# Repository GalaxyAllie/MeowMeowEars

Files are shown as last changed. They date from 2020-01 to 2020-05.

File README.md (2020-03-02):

# Meow Meow Ears

This is a project to create a pair of programmable neko mimis that feature ten LEDs.

## WARNINGS - *max power draw* and *brightness* and *health*

Please be aware that the LEDs can *easily* exceed the max power draw of this circuit design. It is highly recommended not to exceed 150 mA. They're cat ears, you don't need to blind everyone - keep the NeoPixel library brightness down to around 50 or so, tops :)

Also be aware some people are *photo sensitive* - these are meant for rave environments. For environments where people may not expect flashing lights (and where they do...) *please be considerate*.

## Basic Features

- ATSAMD21 microcontroller (ARM Cortext M0)
- Ten WS2812b RGB LEDs
- Power and status LEDs
- One capacitive touch zone - though this isn't used in the example code
- Native USB (you can even use it as a keyboard, hopefully)
- Designed to be put in cat ear headbands. Meow!
- Probably a fair number of bugs and bad design decisions!

## Copyright/Liability

I licence this work under [CC BY-SA 4.0](https://creativecommons.org/licenses/by-sa/4.0/#)

Also, I'm obviously not responsible for injuries or anything like that - this is definitely not a safety-tested, commercial project. Build at your own risk. It probably won't even work :)

## Build Notes

You really shouldn't draw over 50 mA or so of power, you're probably blinding people if you do :) - see warnings above. Thus, you should be fine to input all the way up to the linear regulator max voltage rating of 6V - but you're wasting energy over 3.3V. Thus, 3x NiMH batteries or a 3.7V Lion battery would be good power choices - be smart and sensible though. Batteries can be dangerous. There is no hardware over-discharge protection, so use only batteries with this protection!

Boards can be ordered from [Osh Park](https://oshpark.com/shared_projects/LssyuQtY) - that's not an affiliate link or anything, just a convenient source. And they're purple.

I have forked and modified the Adafruit Trinket M0 file from the Microsoft USB Mass Storage [Bootloader](https://github.com/MermaidAllie/uf2-samdx1/tree/master/build/alliecat_meowmeowears) for the ATSAMD21. The Trinket M0 bootloader also works, tho!

## Bill of Materials

| Component | Manufacturer | Qty |
|---|---|-----|
| This board | Whoever you choose | 1 |
| ATSAMD21E18A-AU-ND | Microchip Technology | 1 |
| S2B-PH-SM4-TB(LF)(SN) | JST | 1 |
| 0.1uF 0603 Capacitor | Any | 10  |
| 1uF 0603 Capacitor | Any | 2 |
| 10uF 0603 Capacitor | Any | 2 |
| WS2812b LED | Worldsemi | 10  |
| UV/blacklight LED 0805 (or fave :) ) | Generic | 2 |
| AP2112K-3.3TRG1 | Diodes Incorporated | 1 |
| BAT54-TP | Micro Commercial Co | 2 |
| USB3076-30-A | GCT | 1 |
| 510 Ohm 0805 Resistor (diff if UV sub)  | Any | 2 |
| 330 Ohm 0805 Resistor | Any | 1 |
| 3.5 x 6 mm push button switch | Generic | 1 |

## Example Code

The example C++/Arduino code is designed to pretend the board is an Adafruit Trinket M0, and is for use with the Trinket M0 bootloader.

## Thanks

Thank you to the following people:

- Ladyada and [Adafruit](https://learn.adafruit.com/how-to-program-samd-bootloaders/trinket-m0-wiring) - for building excellent products and teaching people electronics. I used a lot of Trinket M0's in prototyping this. Seriously, people, go buy their products - they're fantastic (and the boards are way cuter than some others, especially look at the Metro M4 Express - it's just adorable).

- [OpenMoji](https://www.openmoji.org) - this is the source of the emoji used on the board silk.

- Q - for being an awesome friend who has helped with so much of the EDA side of working this all out. Thank you for answering late night messages with silly questions!

- JoJo Siwa - because the inspirational quote comes from one of your songs, and your concert on the [D.R.E.A.M. tour](https://www.jojodreamtour.com/) I went to in Cardiff was amazing. I'm not sure if it's your original quote tho, so I didn't quote it as you - I think I've heard it before? Either way, very inspiring performance! Keep things fun and positive and spread the positive energy, people!

## Version History

### v1

This was essentially a light strip on a cat ear shaped PCB.

### v2

This added an ATSAMD21 microcontroller.

### v3

This is the release version - it fixes the major bugs and makes them ready for general use.

### v3b

Minor update - reset on back where it's useful, more room to insert battery... not much else :)

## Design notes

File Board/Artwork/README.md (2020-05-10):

# Meow Meow Ears Artwork

## OpenMoji

[OpenMoji](https://www.openmoji.org) is the source of the emoji used on the board silk. I have copied the files used in here so you know the source, but please visit OpenMoji to get them for anything you need. OpenMoji are licensed under [CC-BY-SA 4.0](https://creativecommons.org/licenses/by-sa/4.0/#), the same license I use for all my work on this project :) 

## Edge Cuts

The edge cuts files are available as both SVG and [Affinity Designer](https://affinity.serif.com/en-gb/designer/) files.

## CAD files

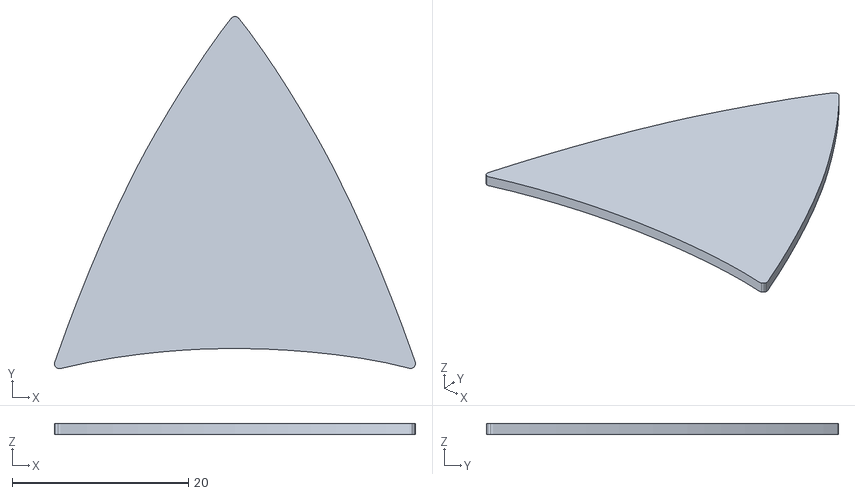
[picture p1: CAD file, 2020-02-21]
Board/Diffuser/Meow Meow Ears - Window.stl
41.0 x 40.0 x 1.20

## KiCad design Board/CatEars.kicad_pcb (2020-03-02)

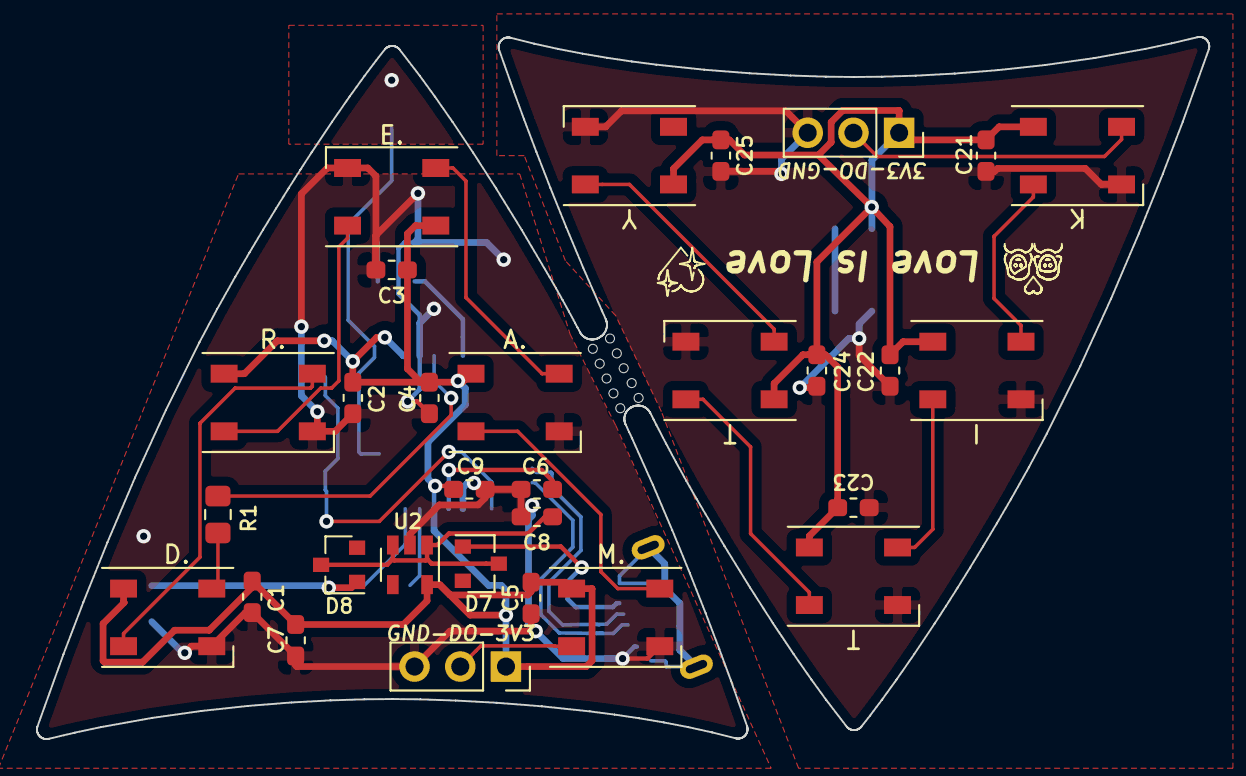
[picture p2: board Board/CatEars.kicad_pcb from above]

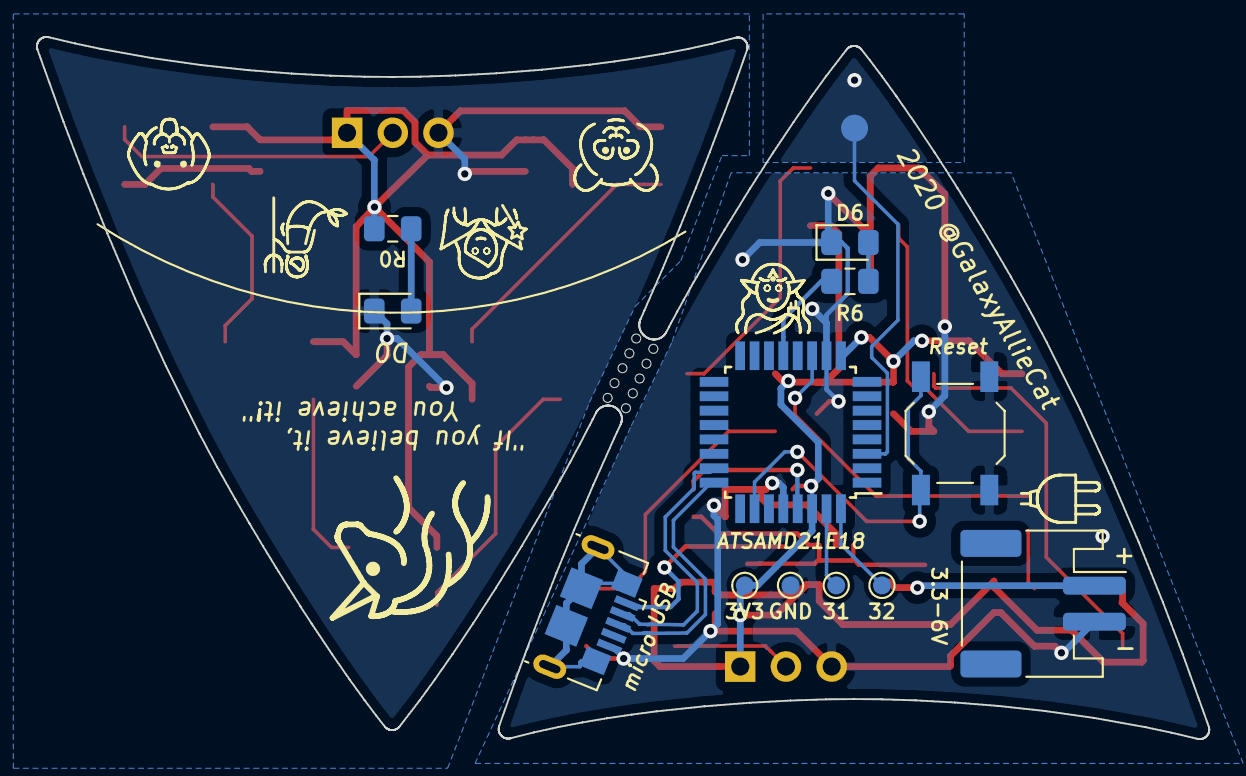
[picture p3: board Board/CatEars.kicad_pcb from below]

Board: 2 copper layers, 65.1 x 39.0 mm, 43 parts (13 on the bottom side), 29 nets.

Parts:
3V3, 31, 32: Conn_01x01; TestPoint_Pad_D1.0mm
3V3-DO-GND: Conn_01x03; PinSocket_1x03_P2.54mm_Vertical
A.: WS2812B; LED_WS2812B_PLCC4_5.0x5.0mm_P3.2mm
ATSAMD21E18: ATSAMD21E18A-AU; TQFP-32_7x7mm_P0.8mm
BT1: Battery; JST_PH_S2B-PH-SM4-TB_1x02-1MP_P2.00mm_Horizontal
C1, C2, C3, C4, C5, C21, C22, C23, C24, C25: 0.1 uF C; C_0603_1608Metric_Pad1.05x0.95mm_HandSolder
C6, C9: 1 uF C; C_0603_1608Metric_Pad1.05x0.95mm_HandSolder
C7, C8: 10 uF C; C_0603_1608Metric_Pad1.05x0.95mm_HandSolder
D0, D6: LED; LED_0805_2012Metric_Pad1.15x1.40mm_HandSolder
D7, D8: D_Schottky; D_SOT-23_ANK
D.: WS2812B; LED_WS2812B_PLCC4_5.0x5.0mm_P3.2mm
E.: WS2812B; LED_WS2812B_PLCC4_5.0x5.0mm_P3.2mm
GND: Conn_01x01; TestPoint_Pad_D1.0mm
GND-DO-3V3: Conn_01x03; PinSocket_1x03_P2.54mm_Vertical
H1: MountingHole_Pad; TestPoint_Pad_D1.5mm
I: WS2812B; LED_WS2812B_PLCC4_5.0x5.0mm_P3.2mm
K: WS2812B; LED_WS2812B_PLCC4_5.0x5.0mm_P3.2mm
M.: WS2812B; LED_WS2812B_PLCC4_5.0x5.0mm_P3.2mm
R0, R6: 510 R; R_0805_2012Metric_Pad1.15x1.40mm_HandSolder
R1: 330 R; R_0805_2012Metric_Pad1.15x1.40mm_HandSolder
R.: WS2812B; LED_WS2812B_PLCC4_5.0x5.0mm_P3.2mm
Reset: SW_Push; SW_SPST_TL3342
T: WS2812B; LED_WS2812B_PLCC4_5.0x5.0mm_P3.2mm
T#2: WS2812B; LED_WS2812B_PLCC4_5.0x5.0mm_P3.2mm
U2: AP2112K-3.3; SOT-23-5
Y: WS2812B; LED_WS2812B_PLCC4_5.0x5.0mm_P3.2mm
micro USB: USB_B_Micro; USB_Micro-B_GCT_USB3076-30-A

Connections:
+3V3: 3V3.1, A..1, ATSAMD21E18.9, ATSAMD21E18.30, C1.1, C2.1, C3.1, C4.1, C5.1, C7.2, C9.1, D..1, E..1, GND-DO-3V3.1, M..1, R..1, U2.5
+BATT: BT1.1, D8.2
/USB_D+: ATSAMD21E18.24, micro USB.3
/USB_D-: ATSAMD21E18.23, micro USB.2
GND: A..3, ATSAMD21E18.10, ATSAMD21E18.28, BT1.2, C1.2, C2.2, C3.2, C4.2, C5.2, C6.1, C7.1, C8.2, C9.2, D6.1, D..3, E..3, GND.1, GND-DO-3V3.3, M..3, R..3, Reset.2, U2.2, micro USB.5
unnamed: ATSAMD21E18.29, C6.2
unnamed: C8.1, D7.1, D8.1, U2.1, U2.3
unnamed: 3V3-DO-GND.1, C21.1, C22.1, C23.1, C24.1, C25.1, I.1, K.1, R0.2, T.1, T#2.1, Y.1
unnamed: 3V3-DO-GND.3, C21.2, C22.2, C23.2, C24.2, C25.2, D0.1, I.3, K.3, T.3, T#2.3, Y.3
unnamed: D0.2, R0.1
unnamed: D..2, R..4
unnamed: D..4, R1.2
unnamed: E..4, R..2
unnamed: A..4, E..2
unnamed: A..2, M..4
unnamed: GND-DO-3V3.2, M..2
unnamed: D6.2, R6.2
unnamed: I.4, K.2
unnamed: 3V3-DO-GND.2, K.4
unnamed: I.2, T.4
unnamed: T.2, T#2.4
unnamed: T#2.2, Y.4
unnamed: ATSAMD21E18.3, H1.1
unnamed: 31.1, ATSAMD21E18.31
unnamed: 32.1, ATSAMD21E18.32
unnamed: ATSAMD21E18.11, R1.1
unnamed: ATSAMD21E18.13, R6.1
unnamed: ATSAMD21E18.26, Reset.1
VBUS: D7.2, micro USB.1

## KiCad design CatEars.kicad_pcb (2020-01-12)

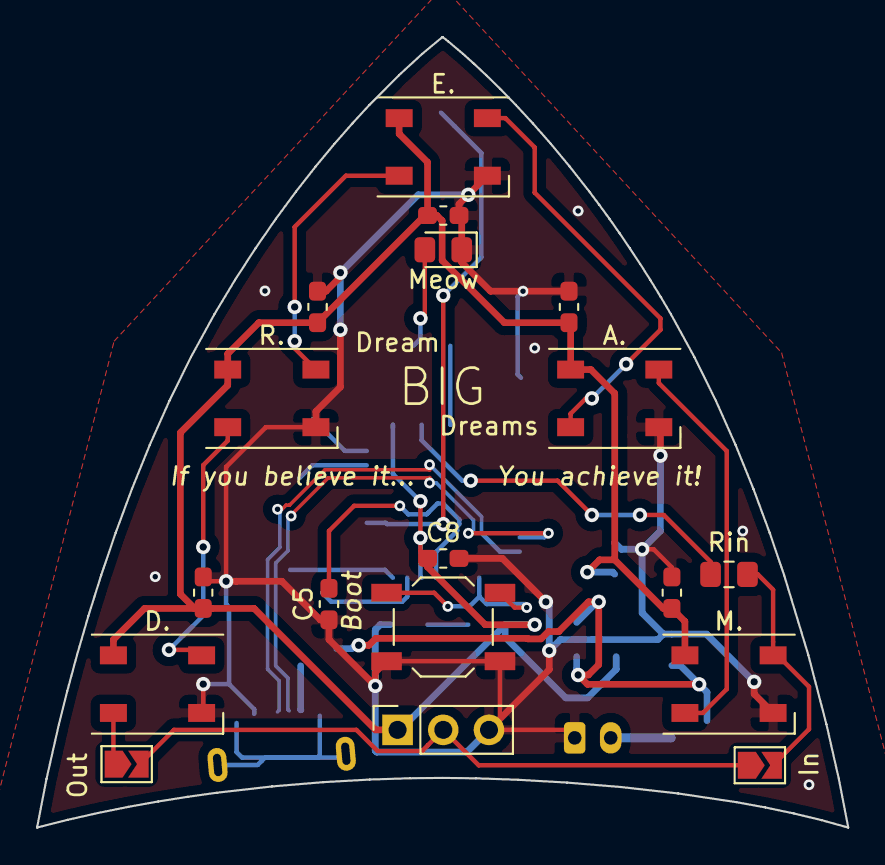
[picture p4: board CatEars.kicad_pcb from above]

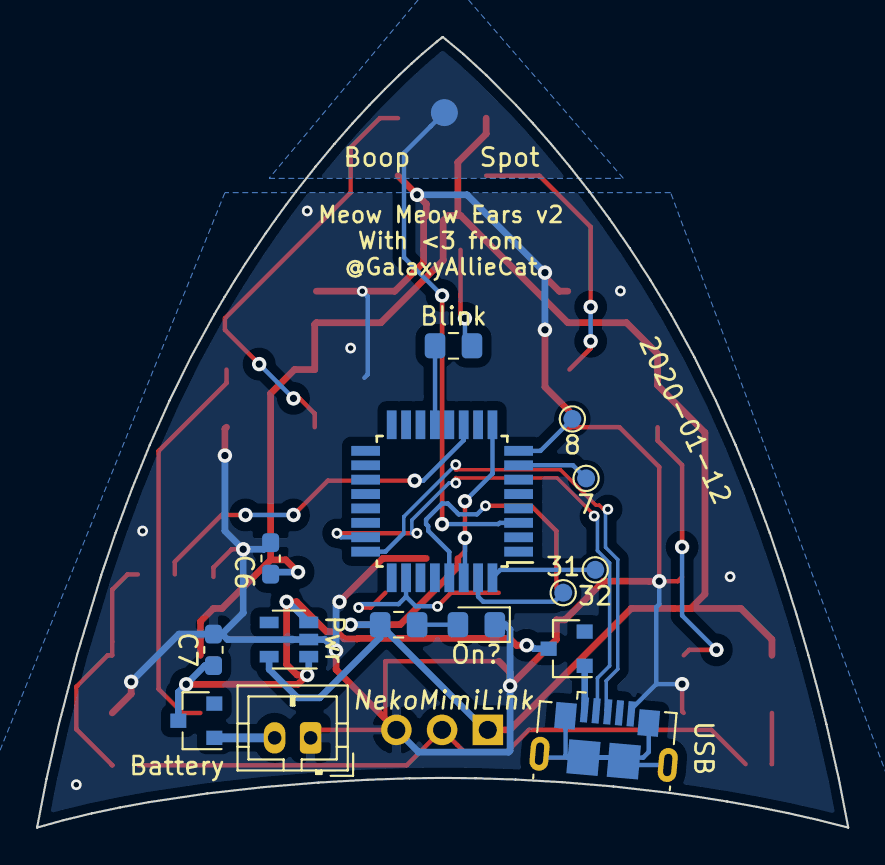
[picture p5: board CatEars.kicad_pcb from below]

Board: 2 copper layers, 45.1 x 43.9 mm, 34 parts (16 on the bottom side), 25 nets.

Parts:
7, 8, 31, 32: Conn_01x01; TestPoint_Pad_D1.0mm
:): USB_B_Micr; USB_Micro-B_GCT_USB3076-30-A
A.: WS2812B; LED_WS2812B_PLCC4_5.0x5.0mm_P3.2mm
Battery: Conn_01x02_Male; JST_PH_B2B-PH-K_1x02_P2.00mm_Vertical
Battery#2: D_Schottky; D_SOT-23_ANK
Blink: R; R_0805_2012Metric_Pad1.15x1.40mm_HandSolder
Boot: SW_Push; SW_SPST_TL3342
C0, C1, C2, C3, C4, C5, C6, C7, C8: C; C_0603_1608Metric_Pad1.05x0.95mm_HandSolder
D.: WS2812B; LED_WS2812B_PLCC4_5.0x5.0mm_P3.2mm
E.: WS2812B; LED_WS2812B_PLCC4_5.0x5.0mm_P3.2mm
H1: MountingHole_Pad; TestPoint_Pad_D1.5mm
In: SolderJumper_2_Open; SolderJumper-2_P1.3mm_Open_TrianglePad1.0x1.5mm
J3: Conn_01x03; PinSocket_1x03_P2.54mm_Vertical
M.: WS2812B; LED_WS2812B_PLCC4_5.0x5.0mm_P3.2mm
Meow: LED; LED_0805_2012Metric_Pad1.15x1.40mm_HandSolder
On?: LED; LED_0805_2012Metric_Pad1.15x1.40mm_HandSolder
Out: SolderJumper_2_Open; SolderJumper-2_P1.3mm_Open_TrianglePad1.0x1.5mm
Pwr: AP2112K-3.3; SOT-23-5
R2: R; R_0805_2012Metric_Pad1.15x1.40mm_HandSolder
R.: WS2812B; LED_WS2812B_PLCC4_5.0x5.0mm_P3.2mm
Rin: R; R_0805_2012Metric_Pad1.15x1.40mm_HandSolder
U1: ATSAMD21E18A-AU; TQFP-32_7x7mm_P0.8mm
USB: D_Schottky; D_SOT-23_ANK

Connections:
+3V3: A..1, C0.1, C1.1, C2.1, C3.1, C4.1, C6.1, C8.1, D..1, E..1, J3.1, M..1, Pwr.5, R2.1, R..1, U1.9, U1.30
+BATT: Battery.2, Battery#2.2
/USB_D+: :).3, U1.24
/USB_D-: :).2, U1.23
GND: :).5, A..3, Battery.1, Boot.2, C0.2, C1.2, C2.2, C3.2, C4.2, C5.1, C6.2, C7.2, C8.2, D..3, E..3, J3.3, M..3, Meow.1, On?.1, Pwr.2, R..3
unnamed: C5.2, U1.29
unnamed: Battery#2.1, C7.1, Pwr.1, Pwr.3, USB.1
unnamed: A..4, M..2
unnamed: In.2, M..4, Rin.2
unnamed: A..2, E..4
unnamed: E..2, R..4
unnamed: D..4, R..2
unnamed: D..2, Out.1
unnamed: Blink.2, Meow.2
unnamed: On?.2, R2.2
unnamed: H1.1, U1.3
unnamed: In.1, J3.2, Out.2
unnamed: 31.1, U1.31
unnamed: 32.1, U1.32
unnamed: 8.1, U1.8
unnamed: 7.1, U1.7
unnamed: Blink.1, U1.13
unnamed: Rin.1, U1.11
unnamed: Boot.1, U1.26
VBUS: :).1, USB.2

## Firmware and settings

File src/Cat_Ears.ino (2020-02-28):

// Sample Arduino code for Meow Meow Ears v3 with Adafruit Trinket M0 bootloader/Arduino board
// Uncomment the code block you wish to run (rainbow uncommented by default)

// Include libraries
#include <Adafruit_NeoPixel.h>
#include <Adafruit_FreeTouch.h>
#include <adafruit_ptc.h>
#include <samd21_ptc_component.h>

// Setup variables

int delayTime = 20;
int redValue = 127;
int greenValue = 0;
int blueValue = 255;
int catSelect = 0;
int colourIncrement = 1;
int pixelDisp = 0;
int modeSel = 0;
int initialTouchValue = 500;
int touchValue = 0;
int counter = 0;

// Configure everything :) 
#define flowerPin 0
#define flowerCount 10

Adafruit_NeoPixel flowers = Adafruit_NeoPixel(flowerCount, flowerPin, NEO_GRB + NEO_KHZ800);
Adafruit_FreeTouch qt_1 = Adafruit_FreeTouch(A0, OVERSAMPLE_4, RESISTOR_50K, FREQ_MODE_NONE);

void setup() {
    Serial.begin(115200);
    flowers.begin();
    flowers.show();
// - USE CAUTION ABOVE BRIGHTNESS 50!!! 
// Linear regulator can get *hot* and battery life will be greatly reduced for little visible difference!
// - NOT recommended to run above 127 (half brightness) as designed
// ...linear regulator may get very hot above 127 brightness depending on light pattern.
    flowers.setBrightness(20);
    if (! qt_1.begin())  
        Serial.println("Failed to begin qt on pin A0");
    initialTouchValue = qt_1.measure();
}

bool capTouchDetect() {
    Serial.println("\n*** Touch Result ***");
    counter = millis();
    touchValue = qt_1.measure(); 
    Serial.print("Right Ear: "); Serial.print(touchValue);
    Serial.print(" (");  Serial.print(millis() - counter); Serial.println(" ms)");   
    if(touchValue > (initialTouchValue + 100)){
        return true;
    }
    else{
        return false;
    }
}

void loop() {
// 
// - Main Loop - uncomment section you want to run - 
// 
// - Rainbow Life -
// 
    if(modeSel == 0)
    {
        for(long firstFlowerColour = 5*65536; firstFlowerColour > 0; firstFlowerColour -= 256) {
            for(int pixelSel = 0; pixelSel < flowerCount; pixelSel++){
                int colourSel = firstFlowerColour + (pixelSel * 65536L / flowerCount);
                uint32_t rainbowSel = flowers.gamma32(flowers.ColorHSV(colourSel));
                flowers.setPixelColor(pixelSel, rainbowSel);
            }
            flowers.show();
            if(capTouchDetect() == true){
                delay(50);
                if(capTouchDetect() == true){
                    modeSel += 1;
                    delay(200);
                }
            }
            if(modeSel != 0){
                break;
            }
            delay(delayTime);
              int counter, result = 0;
        }
    }
// 
// - Twinkle Twinkle, Little Star -
// 
    else if (modeSel == 1)
    {    
        for(int pixelSel = 0; pixelSel < flowerCount; pixelSel++){
            int catSelect = random(0, 9);
            if(catSelect == 3){
                flowers.setPixelColor(pixelSel, 0x00FFFFFF);
            }
            else{
                flowers.setPixelColor(pixelSel, 0x00000000);
            }
        }
        flowers.show();
        delay(random(40, 120));
        if(capTouchDetect() == true){
            delay(50);
            if(capTouchDetect() == true){
                modeSel += 1;
                delay(200);
            }
        }
    }
// 
// - Twinkle Twinkle, Little Star: Pink and Purple Edition -
// 
    else if (modeSel == 2)
    {
        for(int pixelSel = 0; pixelSel < flowerCount; pixelSel++){
            catSelect = random(0, 9);
            if(catSelect == 3){
                flowers.setPixelColor(pixelSel, random(32, 255), 0, random(32, 255));
            }
            else{
                flowers.setPixelColor(pixelSel, 0x00000000);
            }
        }
        flowers.show();
        delay(random(55, 140));
        if(capTouchDetect() == true){
            delay(50);
            if(capTouchDetect() == true){
                modeSel += 1;
                delay(200);
            }
        }
    }
    

// 
// - Unicorn Magic -
//     
    else if(modeSel == 3)
    {
        for(int pixelSel = 0; pixelSel < flowerCount; pixelSel++){
            flowers.setPixelColor(pixelSel, 127, 0, blueValue);
        }
        flowers.show();
        delay(delayTime);
        blueValue = blueValue + colourIncrement;
        if(blueValue > 255){
            blueValue = 255;
            colourIncrement = -1;
        }
        if(blueValue < 32){
            blueValue = 32;
            colourIncrement = 1;
        }
        if(capTouchDetect() == true){
            delay(50);
            if(capTouchDetect() == true){
                modeSel += 1;
                delay(200);
            }
        }
    }
// 
// - Under the Sea -
//     
    else if(modeSel == 4)
    {
        for(int pixelSel = 0; pixelSel < flowerCount; pixelSel++){
            flowers.setPixelColor(pixelSel, 0, greenValue, blueValue);
        }
        flowers.show();
        delay(delayTime);
        greenValue = greenValue + colourIncrement;
        blueValue = blueValue - colourIncrement;
        if((greenValue > 255) || (blueValue < 0)){
            greenValue = 255;
            blueValue = 0;
            colourIncrement = -1;
        }
        if((greenValue < 0) || (blueValue > 255)){
            greenValue = 0;
            blueValue = 255;
            colourIncrement = 1;
        }
        if(capTouchDetect() == true){
            delay(50);
            if(capTouchDetect() == true){
                modeSel += 1;
                delay(200);
            }
        }
    }
// 
// - Trans Pride -
//
    else if(modeSel == 5)
    {
        for(int pixelOffset = 0; pixelOffset < flowerCount; pixelOffset++){
            for(int pixelSel = 0; pixelSel < (flowerCount / 5); pixelSel++){
                if((pixelSel + pixelOffset) < flowerCount){
                    pixelDisp = (pixelSel + pixelOffset);
                }
                else{
                    pixelDisp = ((pixelSel + pixelOffset) - flowerCount);
                }
                flowers.setPixelColor(pixelDisp, 31, 31, 255);
            }
            for(int pixelSel = (flowerCount / 5); pixelSel < (2 * (flowerCount / 5)); pixelSel++){
                if((pixelSel + pixelOffset) < flowerCount){
                    pixelDisp = (pixelSel + pixelOffset);
                }
                else{
                    pixelDisp = ((pixelSel + pixelOffset) - flowerCount);
                }
                flowers.setPixelColor(pixelDisp, 191, 0, 100);
            }
            for(int pixelSel = (2 * (flowerCount / 5)); pixelSel < (3 * (flowerCount / 5)); pixelSel++){
                if((pixelSel + pixelOffset) < flowerCount){
                    pixelDisp = (pixelSel + pixelOffset);
                }
                else{
                    pixelDisp = ((pixelSel + pixelOffset) - flowerCount);
                }
                flowers.setPixelColor(pixelDisp, 180, 165, 180);
            }
            for(int pixelSel = (3 * (flowerCount / 5)); pixelSel < (4 * (flowerCount / 5)); pixelSel++){
                if((pixelSel + pixelOffset) < flowerCount){
                    pixelDisp = (pixelSel + pixelOffset);
                }
                else{
                    pixelDisp = ((pixelSel + pixelOffset) - flowerCount);
                }
                flowers.setPixelColor(pixelDisp, 191, 0, 100);
            }
            for(int pixelSel = (4 * (flowerCount / 5)); pixelSel < flowerCount; pixelSel++){
                if((pixelSel + pixelOffset) < flowerCount){
                    pixelDisp = (pixelSel + pixelOffset);
                }
                else{
                    pixelDisp = ((pixelSel + pixelOffset) - flowerCount);
                }
                flowers.setPixelColor(pixelDisp, 31, 31, 255);
            }
            if(capTouchDetect() == true){
                delay(50);
                if(capTouchDetect() == true){
                    modeSel = 0;
                    delay(200);
                }
            }
            if(modeSel != 5){
                break;
            }
            delay(200);
            if(capTouchDetect() == true){
                delay(50);
                if(capTouchDetect() == true){
                    modeSel = 0;
                    delay(200);
                }
            }
            flowers.show();
            delay(200);
            if(capTouchDetect() == true){
                delay(50);
                if(capTouchDetect() == true){
                    modeSel = 0;
                    delay(200);
                }
            }
            delay(200);
            if(capTouchDetect() == true){
                delay(50);
                if(capTouchDetect() == true){
                    modeSel = 0;
                    delay(200);
                }
            }
        }
    }
}

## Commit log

2020-01-10 Cat Ears v1
    [CatEars.kicad_pcb, CatEars.sch]
2020-01-11 Added schematic and copper
    [CatEars.kicad_pcb, CatEars.sch]
2020-01-12 Production Version with MCU - v2
    [CatEars.kicad_pcb]
2020-02-03 Added Board Outline
2020-02-06 v3 PCB final + gerbers
    [CatEars-B_Cu.gbr, CatEars-B_Mask.gbr, CatEars-B_SilkS.gbr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]
2020-02-10 Added more modes to sample code
    Also tested, all modes consume < 50 mA
2020-02-11 Added Single Board Outline
2020-02-11 Fixed BOM
2020-02-28 Capacitive touch enabled :D
2020-02-28 Move to PlatformIO
    [CatEars-B_Cu.gbr, CatEars-B_Mask.gbr, CatEars-B_SilkS.gbr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]
2020-02-28 Structure to allow for both versions in master
    [CatEars-B_Cu.gbr, CatEars-B_Mask.gbr, CatEars-B_SilkS.gbr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]
2020-02-29 Only one version :)
    [CatEars-B_Cu.gbr, CatEars-B_Mask.gbr, CatEars-B_SilkS.gbr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]
2020-03-01 Custom board definition
    Sets correct USB hardware IDs
2020-03-02 Minor board design revision to allow more space to connect battery and easier assembly
    [CatEars-B_Cu.gbr, CatEars-B_Mask.gbr, CatEars-B_Paste.gbr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]
2020-03-02 tiny tweaks, added new link + battery discharge warning
    [CatEars-B_Cu.gbr, CatEars-B_Mask.gbr, CatEars-B_Paste.gbr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]
2020-03-02 New OSH Park link, rev notes, restored reset
    [CatEars-B_Cu.gbr, CatEars-B_Mask.gbr, CatEars-B_Paste.gbr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]
